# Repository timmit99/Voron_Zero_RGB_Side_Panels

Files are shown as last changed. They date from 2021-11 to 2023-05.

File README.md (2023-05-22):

# Voron Zero RGB Side Panels
 ## Side panels for the Voron Zero printer with 16 WS2812 RGB LED's per side.
 
 ### The build below has some [3mm TAP Plastic black LED acrylic](https://www.tapplastics.com/product/plastics/cut_to_size_plastic/black_led_sheet/668) installed INSIDE the frame extrusions to diffuse the LEDs. They are cut per the [DXF](/CAD/diffuserPanel.dxf) and the [PDF](/CAD/diffuserPanel.pdf) in the CAD folder. 
 
 #### NOTE: The notched corners are intended to go in the front corners to allow the panel to clear the bottom blind joint. My prefernce is to have the matte finish towards the inside of the printer as the glossy side is easy to scratch and scratches are very visible.
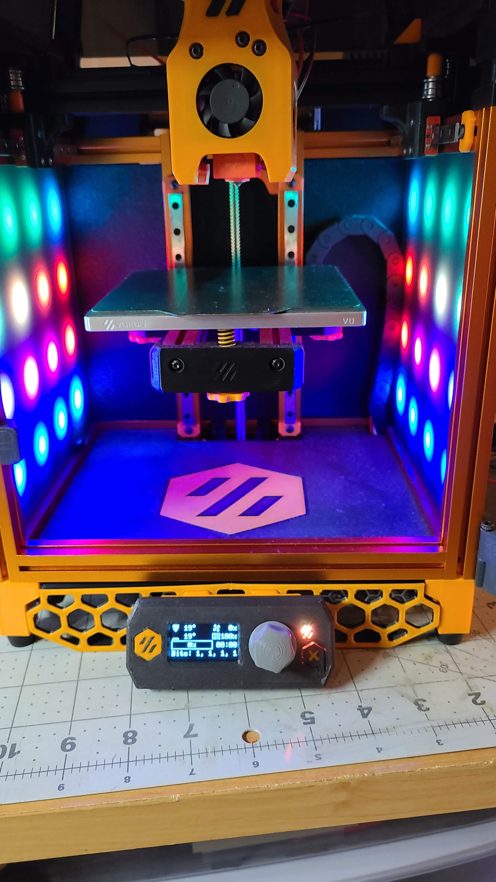
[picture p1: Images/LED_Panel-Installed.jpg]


# I've published the files also over on PCBWays project site!
https://www.pcbway.com/project/shareproject/Voron_Zero_Side_Panel___Left.html

https://www.pcbway.com/project/shareproject/Voron_Zero_Side_Panel___Right.html

## Build steps
1. Order set of PCB's.
2. Order 32 5050 RGB/RGBW LED's.
3. Print replacement panel clips.
4. Assemble PCB's with your choice of 0.1" 6 pin connector (JST-XH, Dupont, bare wire).
5. Plug in and test.
6. DONE!

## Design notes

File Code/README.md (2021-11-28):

You can plug the boards into your printers control board but I wanted external control to move all timing sensitive commands off of the Raspberry Pi as to not interfere with printing. That's why I made the 4 bit parallel interface code as well as the corresponding decoder on the Arduino. If Klipper adds some direct I2C commands in the future I will most definitely switch to that for ease of coding and simplicity.

This is just **MY** example code, feel free to add, modify, or write your own to control the colors. Please share it back here; I’d love to see what you create!

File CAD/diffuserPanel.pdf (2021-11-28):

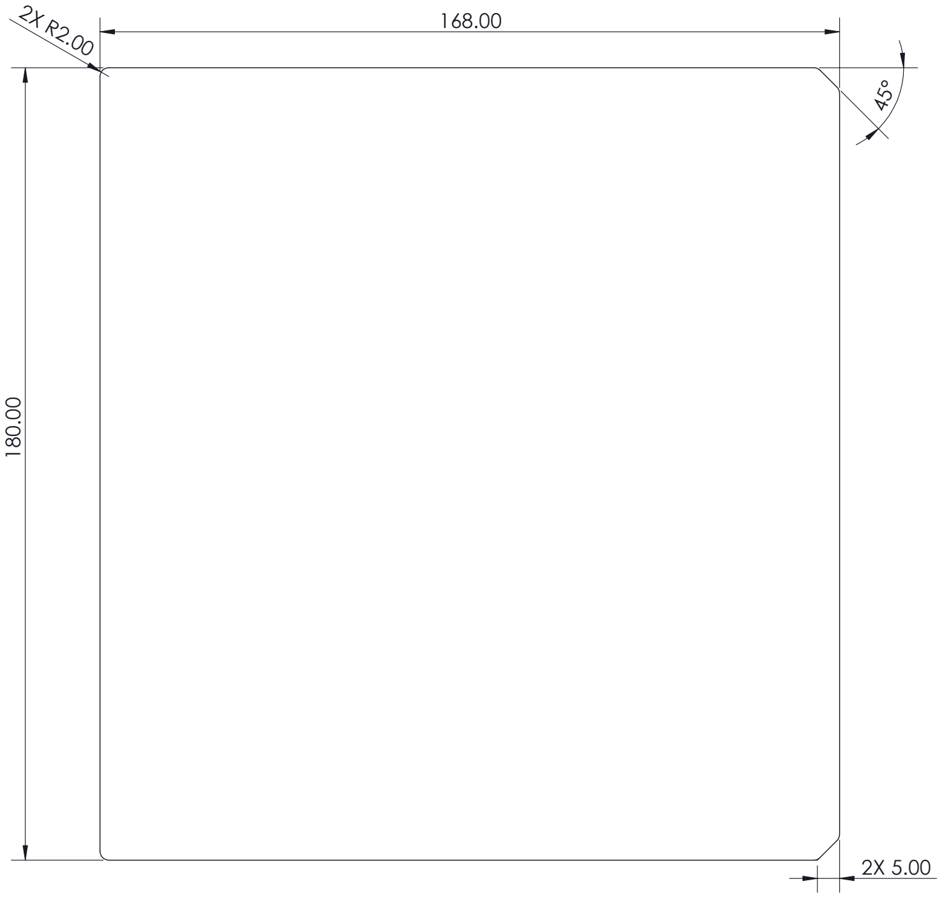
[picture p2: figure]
2X 5.00 ¹⁸⁰.00

SOLIDWORKS Educational Product. For Instructional Use Only.

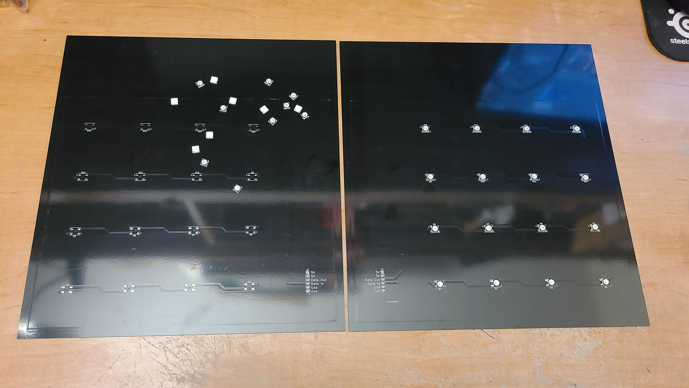
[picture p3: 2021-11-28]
Images/LED_Panel-PCB_Overview.jpg

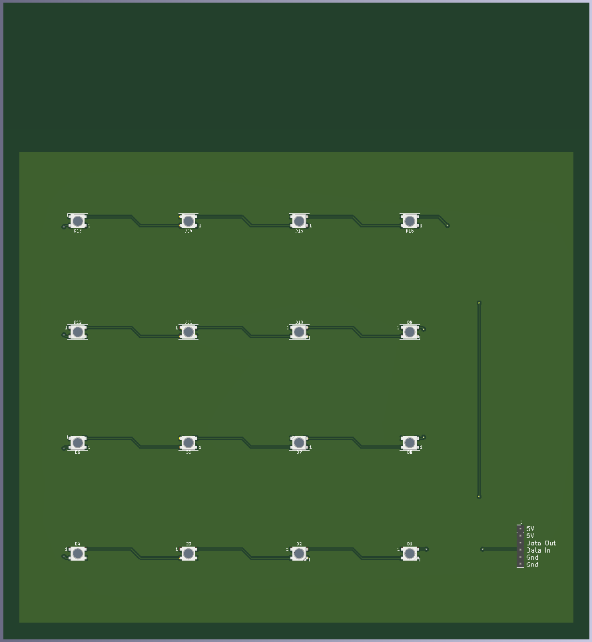
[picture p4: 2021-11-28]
Images/LeftPanel.png

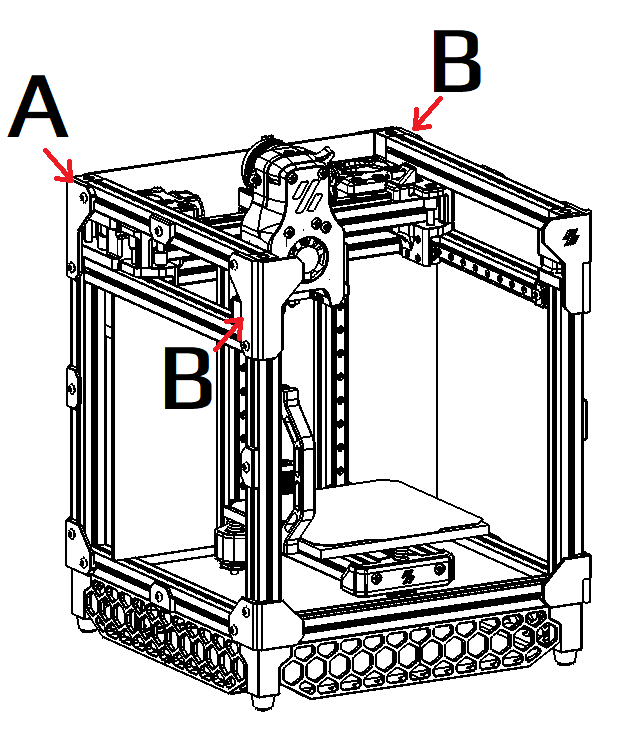
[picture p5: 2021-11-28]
Images/STL_Naming.png

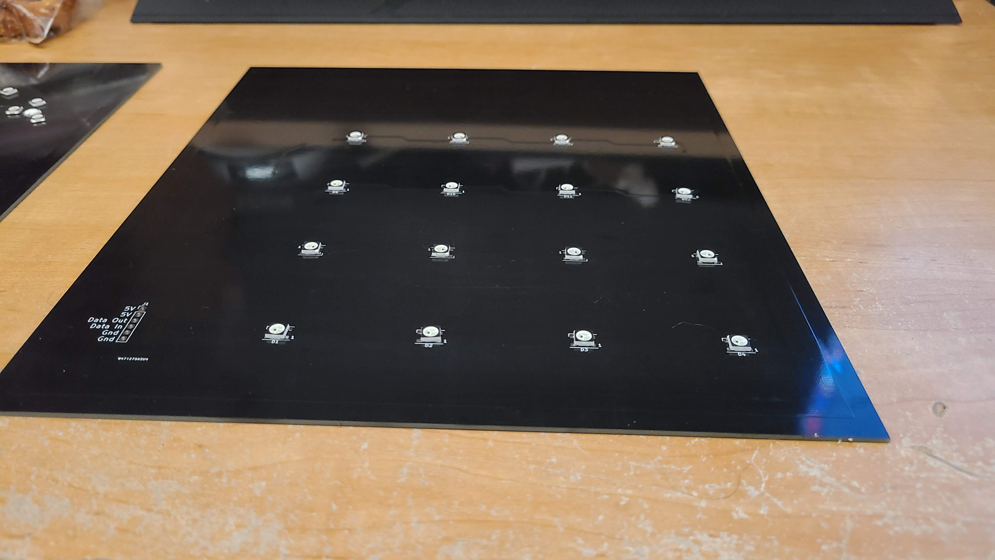
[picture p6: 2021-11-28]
Images/LED_Panel-PCB_Closeup.jpg

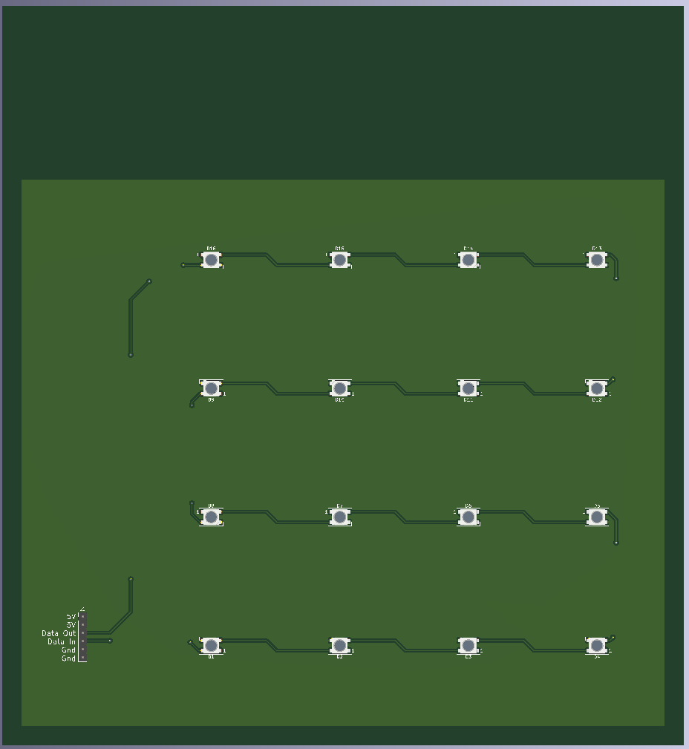
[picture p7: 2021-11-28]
Images/RightPanel.png

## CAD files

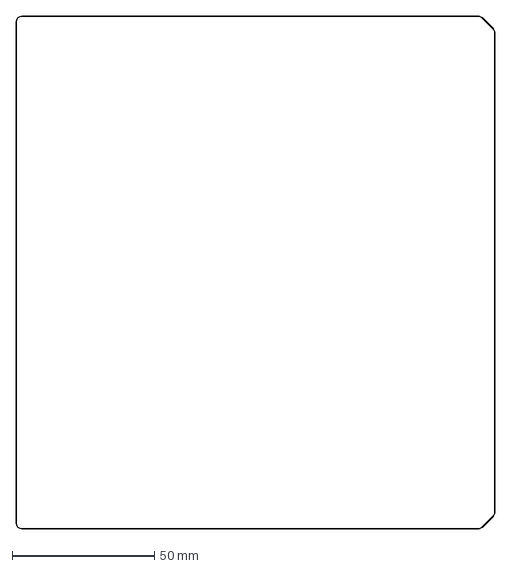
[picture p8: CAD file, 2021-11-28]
CAD/diffuserPanel.dxf
168.0 x 180.0 mm

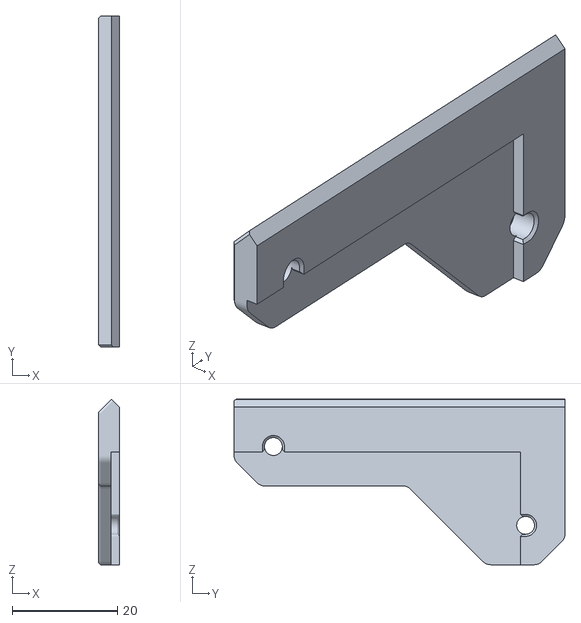
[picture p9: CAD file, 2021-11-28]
STL's/Panel_Clip_Corner_Top_B_x2.STL
4.00 x 63.0 x 31.5

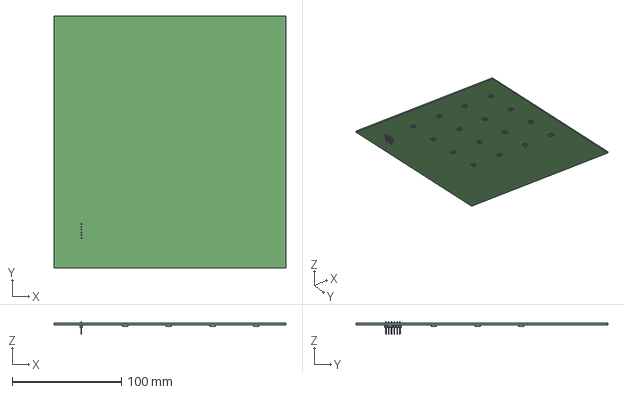
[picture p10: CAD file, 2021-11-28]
CAD/LEFT_Side Panel.step
212.0 x 230.0 x 11.5 mm

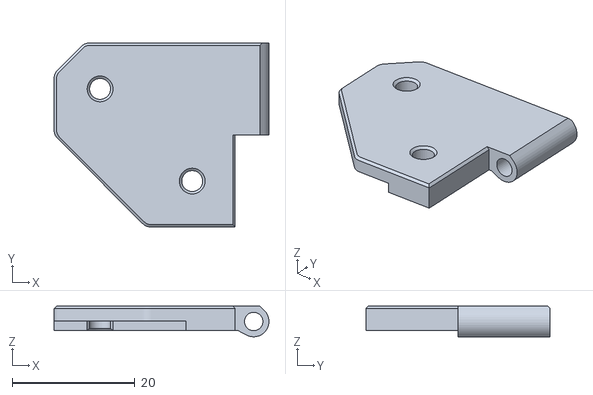
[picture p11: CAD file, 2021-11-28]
STL's/Panel_Clip_Corner_Bottom_Hinge_x1.STL
35.0 x 30.0 x 5.00

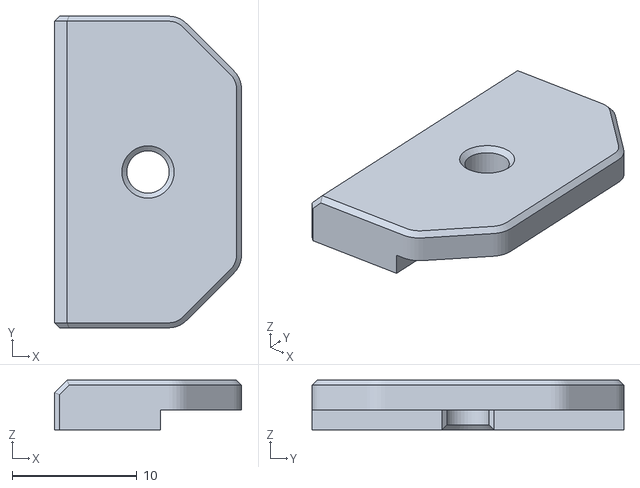
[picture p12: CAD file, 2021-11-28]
STL's/Panel_Clip_Middle_x8.STL
15.0 x 25.0 x 4.00

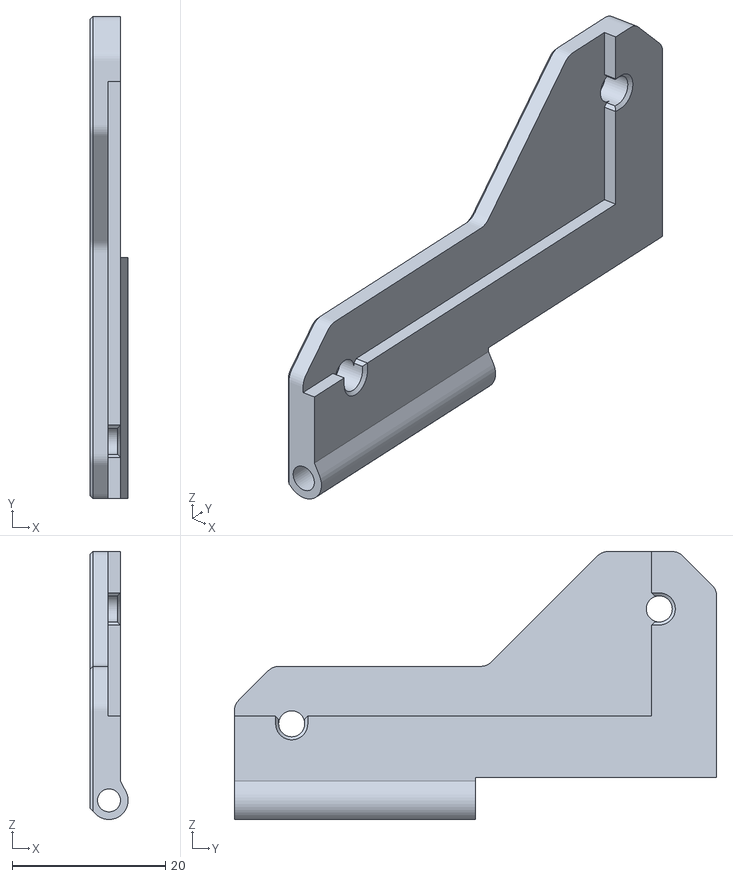
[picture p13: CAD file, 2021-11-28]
STL's/Panel_Clip_Corner_Top_Hinge_x1.STL
5.00 x 63.0 x 35.0

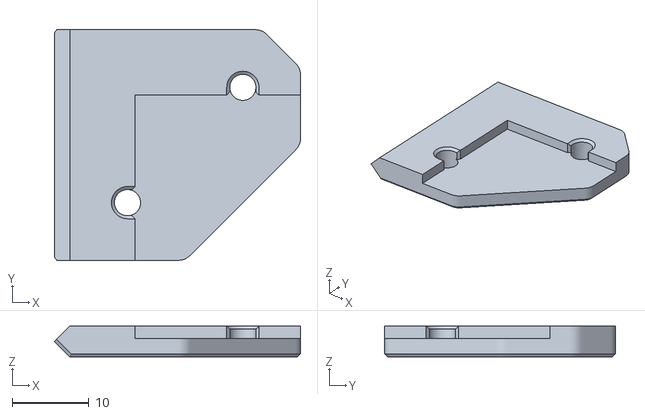
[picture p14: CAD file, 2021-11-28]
STL's/Panel_Clip_Corner_Bottom_A_x1.STL
32.0 x 30.0 x 4.00

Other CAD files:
CAD/RIGHT_Side Panel.step
STL's/Panel_Clip_Corner_Top_A_x1.STL
STL's/Panel_Clip_Corner_Bottom_B_x2.STL

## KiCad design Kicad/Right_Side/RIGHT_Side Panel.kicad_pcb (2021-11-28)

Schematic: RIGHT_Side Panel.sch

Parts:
D1, D2, D3, D4, D5, D6, D7, D8, D9, D10, D11, D12, D13, D14, D15, D16: WS2812B; LED_WS2812B_PLCC4_5.0x5.0mm_P3.2mm
J1: Conn_01x06; PinHeader_1x06_P2.54mm_Vertical

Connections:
+5V: D1.1 (VDD), D2.1 (VDD), D3.1 (VDD), D4.1 (VDD), D5.1 (VDD), D6.1 (VDD), D7.1 (VDD), D8.1 (VDD), D9.1 (VDD), D10.1 (VDD), D11.1 (VDD), D12.1 (VDD), D13.1 (VDD), D14.1 (VDD), D15.1 (VDD), D16.1 (VDD), J1.1, J1.2
Data_in: D1.4 (DIN), J1.4
Data_out: D16.2 (DOUT), J1.3
GND: D1.3 (VSS), D2.3 (VSS), D3.3 (VSS), D4.3 (VSS), D5.3 (VSS), D6.3 (VSS), D7.3 (VSS), D8.3 (VSS), D9.3 (VSS), D10.3 (VSS), D11.3 (VSS), D12.3 (VSS), D13.3 (VSS), D14.3 (VSS), D15.3 (VSS), D16.3 (VSS), J1.5, J1.6
unnamed: D1.2 (DOUT), D2.4 (DIN)
unnamed: D2.2 (DOUT), D3.4 (DIN)
unnamed: D3.2 (DOUT), D4.4 (DIN)
unnamed: D4.2 (DOUT), D5.4 (DIN)
unnamed: D5.2 (DOUT), D6.4 (DIN)
unnamed: D6.2 (DOUT), D7.4 (DIN)
unnamed: D7.2 (DOUT), D8.4 (DIN)
unnamed: D8.2 (DOUT), D9.4 (DIN)
unnamed: D10.2 (DOUT), D11.4 (DIN)
unnamed: D9.2 (DOUT), D10.4 (DIN)
unnamed: D11.2 (DOUT), D12.4 (DIN)
unnamed: D12.2 (DOUT), D13.4 (DIN)
unnamed: D13.2 (DOUT), D14.4 (DIN)
unnamed: D14.2 (DOUT), D15.4 (DIN)
unnamed: D15.2 (DOUT), D16.4 (DIN)

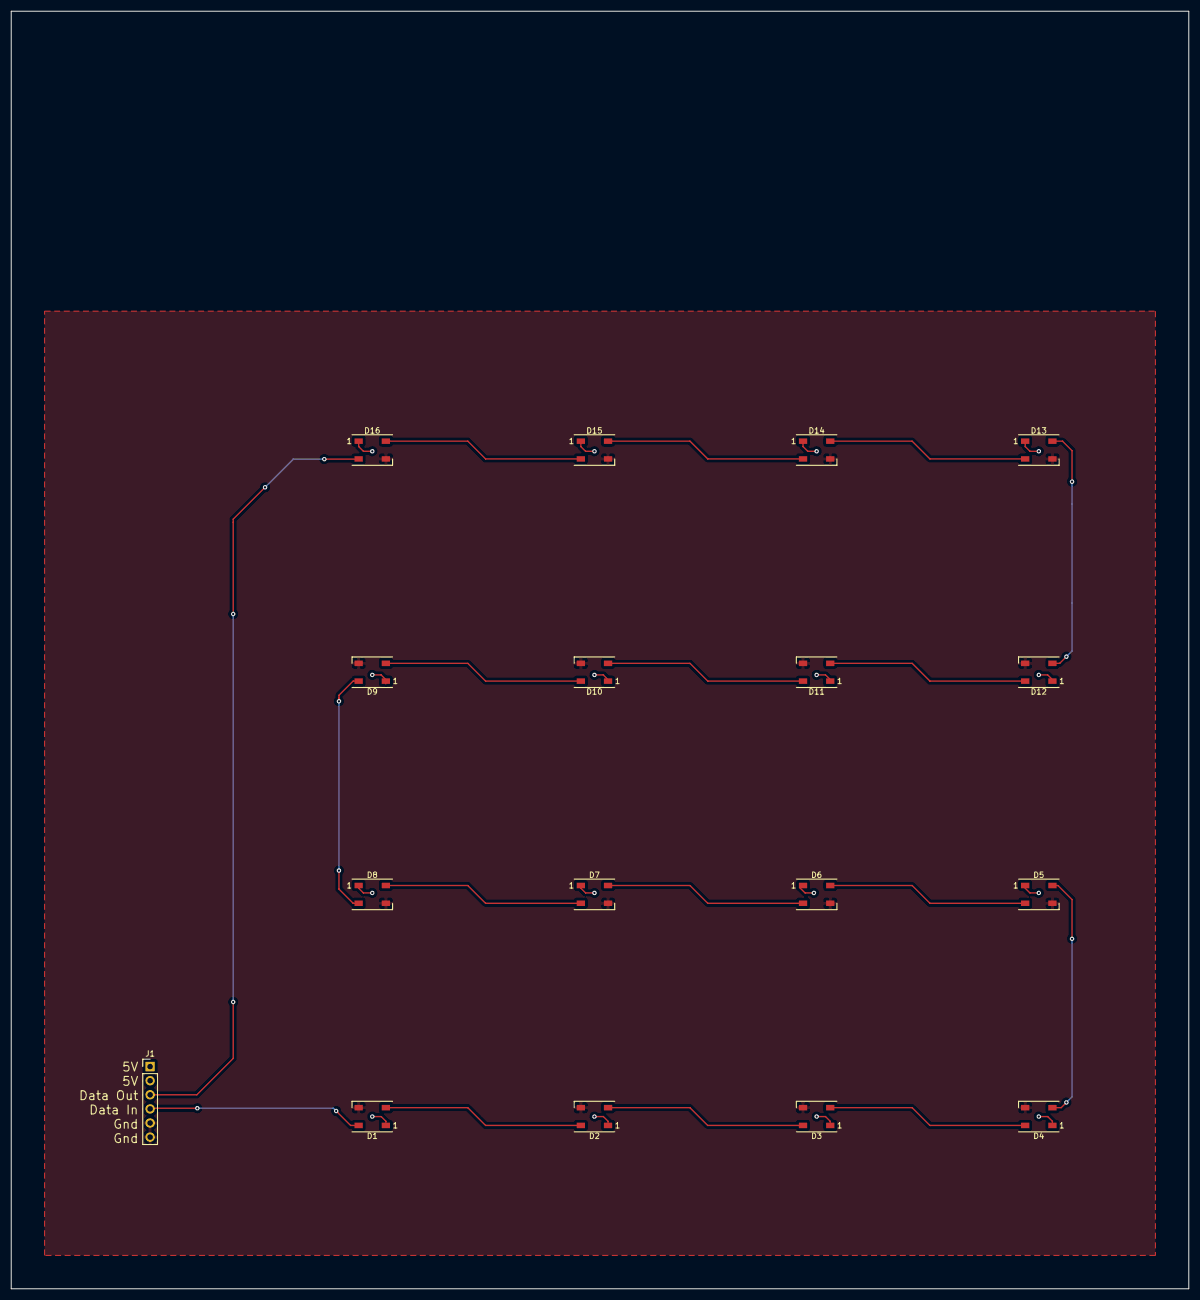
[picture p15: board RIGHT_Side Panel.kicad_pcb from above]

Board: 2 copper layers, 212.0 x 230.0 mm, 17 parts (0 on the bottom side), 19 nets.

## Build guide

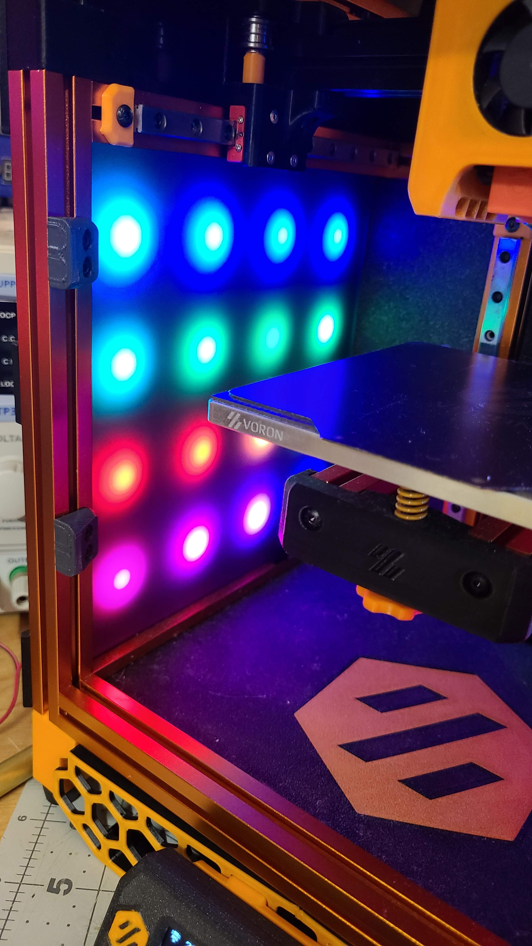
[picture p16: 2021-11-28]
Images/LED_Panel-Installed2.jpg

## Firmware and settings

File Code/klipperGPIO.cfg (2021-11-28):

[mcu host]
serial: /tmp/klipper_host_mcu

[output_pin clock]
pin: host:gpio26
value:1 
# Keep clock pin high normally as the arduino expects a falling edge pulse

[output_pin D0]
pin: host:gpio5

[output_pin D1]
pin: host:gpio6 

[output_pin D2]
pin: host:gpio13 

[output_pin D3]
pin: host:gpio19 

[gcode_macro set_GPIO]
gcode:
    {% set GPIO_value = params.GPIO|default(0)|int %}
    {% set Data0 = 0 %} # LSB
    {% set Data1 = 0 %} #
    {% set Data2 = 0 %} #
    {% set Data3 = 0 %} # MSB
    # If the data is GREATER than or equal to 8, set Data3 (MSB) to 1 and subtract 8
    {% if  (GPIO_value <= 15) %}

    {% if  (GPIO_value >= 8) %}
    {% set Data3 = 1 %}
    {% set GPIO_value = GPIO_value-8 %}
    {% endif %}
    # If the new data is GREATER than or equal to 4, set Data2 to 1 and subtract 4
    {% if  (GPIO_value >= 4)  %}
    {% set Data2 = 1 %}
    {% set GPIO_value = GPIO_value-4 %}
    {% endif %}
    # If the new data is GREATER than or equal to 2, set Data3 (MSB) to 1 and subtract 2
    {% if  (GPIO_value >= 2)  %}
    {% set Data1 = 1 %}
    {% set GPIO_value = GPIO_value-2 %}
    {% endif %}
    # If the new data is equal to 1, set Data0 (LSB) to 1
    {% if  (GPIO_value == 1)  %}
    {% set Data0 = 1 %}
    {% endif %}
    {% endif %}


    SET_PIN PIN=D0 VALUE={Data0}
    SET_PIN PIN=D1 VALUE={Data1}
    SET_PIN PIN=D2 VALUE={Data2}
    SET_PIN PIN=D3 VALUE={Data3}
# pulse the clock to trigger the target interupt
    SET_PIN PIN=clock VALUE=0
    SET_PIN PIN=clock VALUE=1

    M117 Bits: {Data3}, {Data2}, {Data1}, {Data0}


# 0 = Off
# 1 = Red
# 2 = Orange
# 3 = Yellow
# 4 = Green
# 5 = Blue
# 6 = Purple
# 7 = White
# 8 = Christmas
# 9 = ?
# 10 = ?
# 11 = ?
# 12 = ?
# 13 = ?
# 14 = ?
# 15 = Rainbow 
    

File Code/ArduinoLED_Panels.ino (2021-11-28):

/*
  Voron Zero WS2812 Side panel control code
  Timothy Abraham - 11/27/2021


  Connect 4 bits of data between pins 3(MSB) -> 6(LSB)
  Connect clock pin to digital 2
  Connect Neopixel panel(s) to pin 8


  Patterns used from Adafruit Neopixel example code
*/
#include <Adafruit_NeoPixel.h>
#define LED_PIN    8
// How many NeoPixels are attached to the Arduino?
#define LED_COUNT 16

int data0 = 6; //LSB
int data1 = 5;
int data2 = 4;
int data3 = 3; //MSB
int clockPin = 2;
int data = 0;
int dataChange = 0;

Adafruit_NeoPixel strip(LED_COUNT, LED_PIN, NEO_GRB + NEO_KHZ800);

// the setup routine runs once when you press reset:
void setup() {
  // initialize serial communication at 9600 bits per second:
  Serial.begin(9600);
  // make the data pins inputs:
  pinMode(data0, INPUT);
  pinMode(data1, INPUT);
  pinMode(data2, INPUT);
  pinMode(data3, INPUT);
  pinMode(clockPin, INPUT_PULLUP); // and add pullup to clock pin
  attachInterrupt(digitalPinToInterrupt(clockPin), getData, FALLING);
  //attach a falling edge trigger interupt ot the clock pin

  strip.begin();           // INITIALIZE NeoPixel strip object (REQUIRED)
  strip.show();            // Turn OFF all pixels ASAP
  strip.setBrightness(150); // Set BRIGHTNESS to about 1/5 (max = 255)

  // Flash orange to show everything is working correctly!
  colorWipe(strip.Color(255,   50,   0), 40); // Orange
  colorWipe(strip.Color(0,   0,   0), 40); // Off
  colorWipe(strip.Color(255,   50,   0), 40); // Orange
  colorWipe(strip.Color(0,   0,   0), 40); // Off
}

// the loop routine runs over and over again forever:
void loop() {
  // read the input pin:
  if (dataChange) { // If the interupt is triggered and the data has changed
    Serial.println(data); // Print the input data out over serial (for debugging)
    dataChange = 0; // reset dataChange to 0 to signal that the data has been read in
  }

  switch (data) {
    case 1:
      colorWipe(strip.Color( 255,   0,   0), 50); // Red
      break;
    case 2:
      colorWipe(strip.Color( 255, 120,   0), 50); // Orange
      break;
    case 3:
      colorWipe(strip.Color( 255, 255,   0), 50); // Yellow
      break;
    case 4:
      colorWipe(strip.Color(   0, 255,   0), 50); // Green
      break;
    case 5:
      colorWipe(strip.Color(   0,   0, 255), 50); // Blue
      break;
    case 6:
      colorWipe(strip.Color( 255,   0, 255), 50); // Purple
      break;
    case 7:
      colorWipe(strip.Color( 255, 255, 255), 50); // White
      break;
    case 8:
      christmasLights(750); // flash red and green on alternate pixels
      break;
    case 15:
      rainbow(10);
      break;
    default:
      colorWipe(strip.Color( 0, 0, 0), 50); // Off (for anything that ISN'T defined above
      break;
      delay(1);        // delay in between reads for stability
  }
}

void getData() {
  //BitWrite the data from the 4 data pins into the "data" intiger
  bitWrite(data, 0, digitalRead(data0));
  bitWrite(data, 1, digitalRead(data1));
  bitWrite(data, 2, digitalRead(data2));
  bitWrite(data, 3, digitalRead(data3));
  dataChange = 1; // set the data change flag to triger on the next loop iteration and break from any loops in the patterns
}

void colorWipe(uint32_t color, int wait) {
  for (int i = 0; i < strip.numPixels(); i++) { // For each pixel in strip...
    strip.setPixelColor(i, color);         //  Set pixel's color (in RAM)
    strip.show();                          //  Update strip to match
    if (dataChange) {
      return;
    }
    delay(wait);                           //  Pause for a moment
  }
}

void theaterChase(uint32_t color, int wait) {
  for (int a = 0; a < 10; a++) { // Repeat 10 times...
    for (int b = 0; b < 3; b++) { //  'b' counts from 0 to 2...
      strip.clear();         //   Set all pixels in RAM to 0 (off)
      // 'c' counts up from 'b' to end of strip in steps of 3...
      for (int c = b; c < strip.numPixels(); c += 3) {
        strip.setPixelColor(c, color); // Set pixel 'c' to value 'color'
        if (dataChange) {
          return;
        }
      }
      strip.show(); // Update strip with new contents
      delay(wait);  // Pause for a moment
    }
  }
}

void rainbow(int wait) {
  // Hue of first pixel runs 5 complete loops through the color wheel.
  // Color wheel has a range of 65536 but it's OK if we roll over, so
  // just count from 0 to 5*65536. Adding 256 to firstPixelHue each time
  // means we'll make 5*65536/256 = 1280 passes through this outer loop:
  for (long firstPixelHue = 0; firstPixelHue < 5 * 65536; firstPixelHue += 256) {
    for (int i = 0; i < strip.numPixels(); i++) { // For each pixel in strip...
      // Offset pixel hue by an amount to make one full revolution of the
      // color wheel (range of 65536) along the length of the strip
      // (strip.numPixels() steps):
      int pixelHue = firstPixelHue + (i * 65536L / strip.numPixels());
      // strip.ColorHSV() can take 1 or 3 arguments: a hue (0 to 65535) or
      // optionally add saturation and value (brightness) (each 0 to 255).
      // Here we're using just the single-argument hue variant. The result
      // is passed through strip.gamma32() to provide 'truer' colors
      // before assigning to each pixel:
      strip.setPixelColor(i, strip.gamma32(strip.ColorHSV(pixelHue)));
      if (dataChange) {
        return;
      }
    }
    strip.show(); // Update strip with new contents
    delay(wait);  // Pause for a moment
  }
}

void christmasLights(int wait) {
  for (int i = 0; i < strip.numPixels(); i += 2) {
    strip.setPixelColor(i,     strip.Color( 255,   0,   0)); // Set every even pixel to red.
    strip.setPixelColor(i + 1, strip.Color(   0, 255,   0)); // Set every odd pixel to green
    if (dataChange) {
      return;
    }
  }
  strip.show(); // Update strip with new contents
  delay(wait);  // Pause for a moment
  for (int i = 0; i < strip.numPixels(); i += 2) {
    strip.setPixelColor(i,     strip.Color(   0, 255,   0)); // Set every even pixel to green.
    strip.setPixelColor(i + 1, strip.Color( 255,   0,   0)); // Set every odd pixel to red
    if (dataChange) {
      return;
    }

  }
  strip.show(); // Update strip with new contents
  delay(wait);  // Pause for a moment
}

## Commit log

2021-11-28 Initial Commit of PCB's and CAD
    [LEFT_Side Panel-B_Cu.gbr, LEFT_Side Panel-B_Mask.gbr, LEFT_Side Panel-B_Paste.gbr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]
2021-11-28 Add code examples for controlling with the Klipper RasPi
    [klipperGPIO.cfg]
